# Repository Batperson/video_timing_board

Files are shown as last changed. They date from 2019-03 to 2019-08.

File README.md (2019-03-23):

# Video Timing Board
A Development board to extract timing and subcarrier signals from a composite PAL or NTSC video source.

This is part of my ongoing project to develop a system to superimpose colour text and graphics from a microcontroller onto a composite TV signal. My earlier experimenter's board which can be found at https://github.com/Batperson/video_experimenters_board used a high-speed digital decoder and encoder connected back-to-back, but I now want to try some different methods.

One method is to use an AD724 chip from Analog Devices to generate composite video from RGB signals supplied by a microcontroller. If the AD724 is driven by a clock synchronised with an incoming video signal's colour subcarrier, then its output will also be synchronised with that same subcarrier (i.e. genlocked). Then, a fast switch can be used to switch between the incoming video signal and the text/graphic video signal which we wish to superimpose.

Another method is to generate composite video directly from a microcontroller using the SPI output. Rossum at https://rossumblog.com/2010/06/10/rbox-a-diy-32-bit-game-console-for-the-price-of-a-latte/ has already demonstrated this with the most impressive RBox, a game console based on the Arm Cortex M0 which generates full-colour composite video without any supporting ICs. My theory is that I can do the same, but supply an external clock to the SPI. If this clock is derived from an incoming video signal's colourburst then the output should be genlocked..

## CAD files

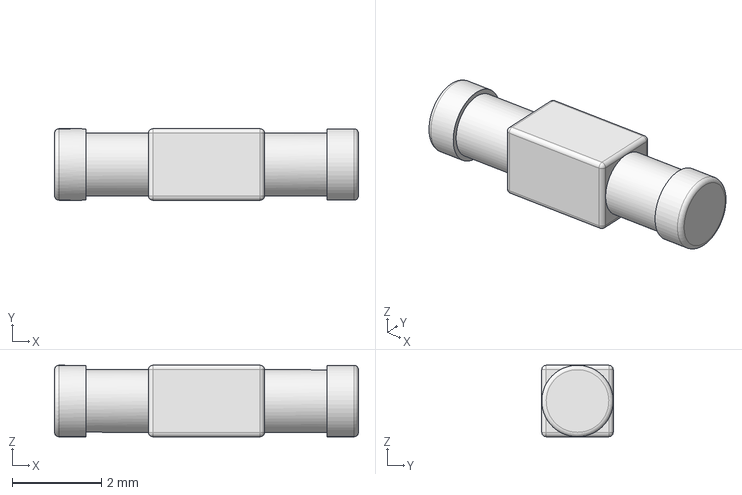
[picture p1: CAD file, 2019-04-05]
3D/NFE61PT472C1H9L.stp
6.80 x 1.60 x 1.60 mm

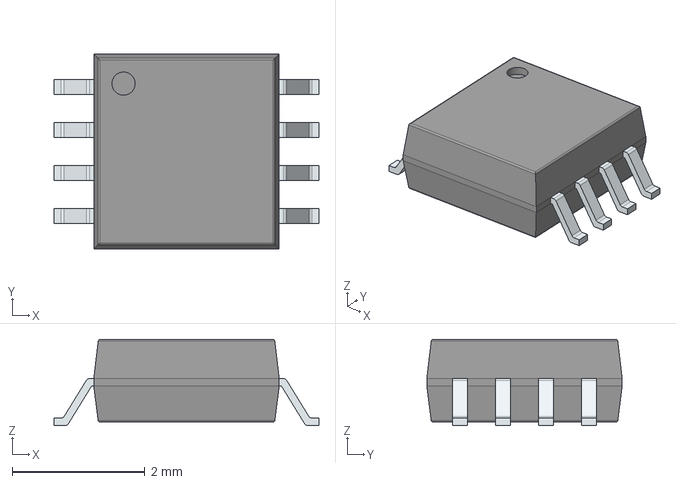
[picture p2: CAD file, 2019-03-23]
3D/SN74LVC3G04DCTR.stp
4.00 x 2.95 x 1.30 mm
PinsArrayLR

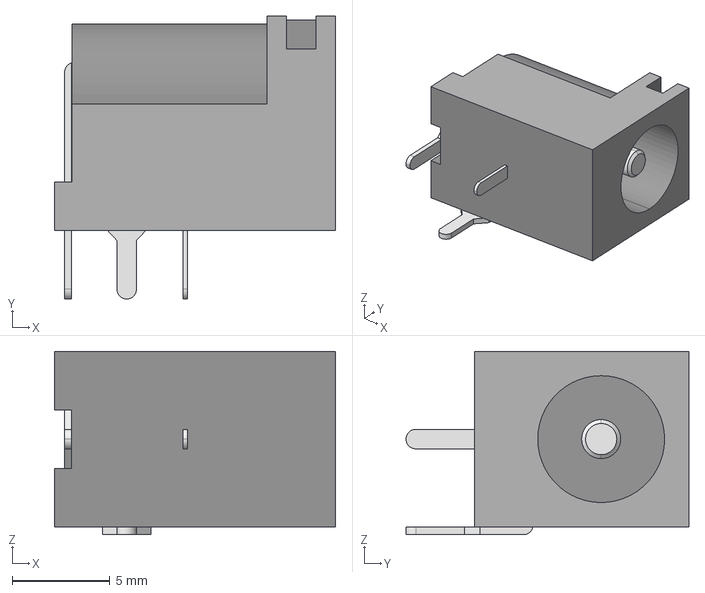
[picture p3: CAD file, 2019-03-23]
3D/PJ-102A.stp
14.4 x 14.5 x 9.40 mm

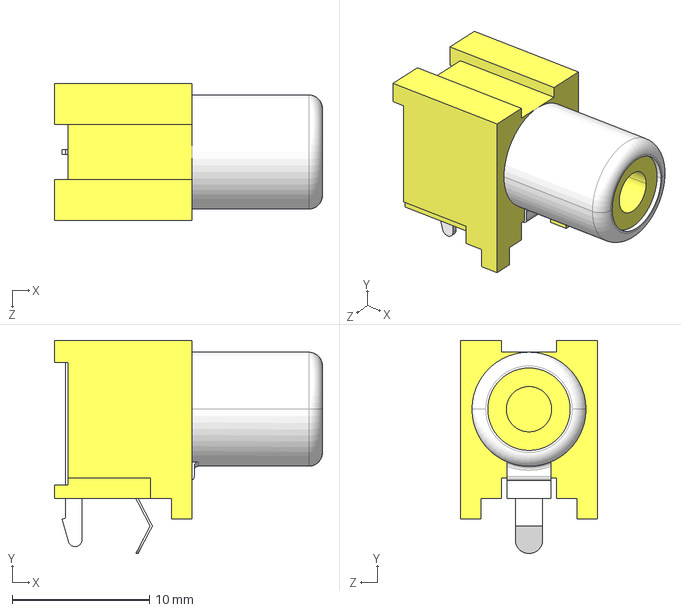
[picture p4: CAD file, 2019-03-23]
3D/CUI_RCJ-044.stp
19.5 x 15.5 x 10.0 mm

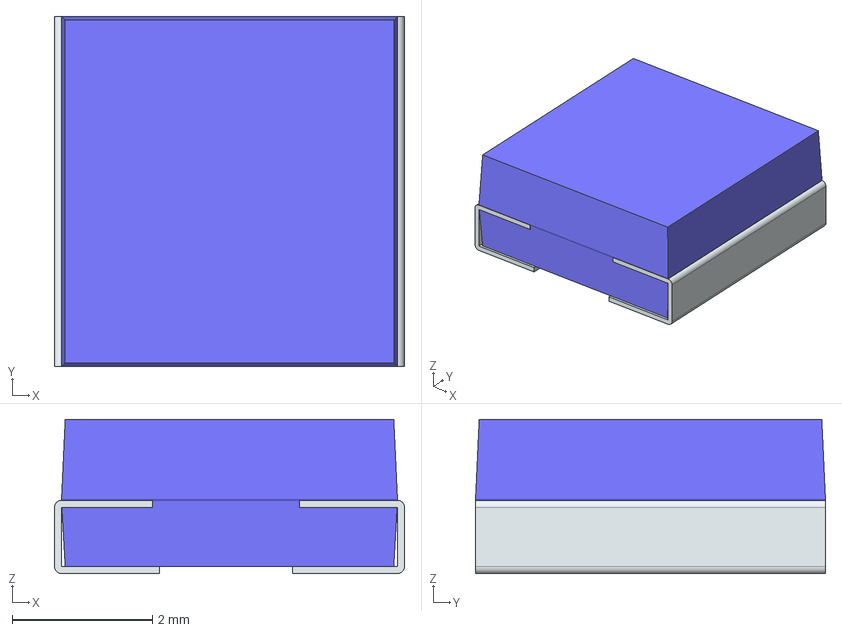
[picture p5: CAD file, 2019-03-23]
3D/LQH5BPN3R3NT0L.stp
5.00 x 5.00 x 2.20 mm
FilletPin1
FilletPin2

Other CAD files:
3D/LQH5BPN3R3NT0L.stl
3D/SN74LVC3G04DCTR.stl

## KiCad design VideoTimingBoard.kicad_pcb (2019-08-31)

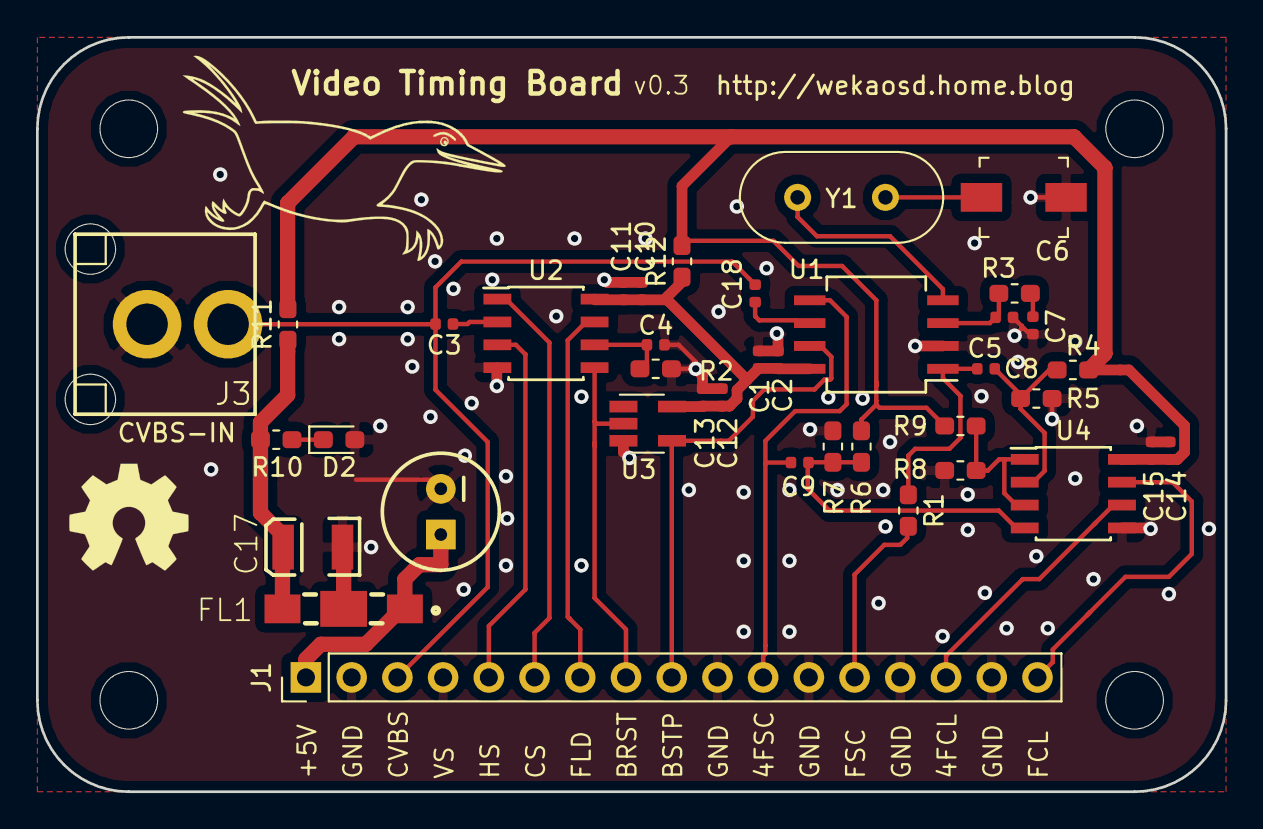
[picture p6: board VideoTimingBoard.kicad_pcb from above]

Board: 2 copper layers, 66.0 x 41.9 mm, 39 parts (0 on the bottom side), 25 nets.

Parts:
C1, C10, C12, C14: 10uF; C_0402_1005Metric
C2, C3, C4, C7, C11, C13, C15, C18: 0.1uF; C_0402_1005Metric
C5: 470pF; C_0402_1005Metric
C6: 5-25pF; C_Trimmer_Murata_TZB4-A
C8, C9: 1nF; C_0402_1005Metric
C16: 220uF; CPOL-RADIAL
C17: 33uF; EIA3528
D2: LED_0603_1608Metric_Pad1.05x0.95mm_HandSolder
FL1: NFE61PT472C1H9L; 6816
J1: PinHeader_1x17_P2.54mm_Vertical
J3: RCA
R1, R11: 0R; R_0603_1608Metric_Pad1.05x0.95mm_HandSolder
R2: 680K; R_0603_1608Metric_Pad1.05x0.95mm_HandSolder
R3: 47K; R_0603_1608Metric_Pad1.05x0.95mm_HandSolder
R4, R5, R6, R7, R8, R9: 10K; R_0603_1608Metric_Pad1.05x0.95mm_HandSolder
R10: 150R; R_0603_1608Metric_Pad1.05x0.95mm_HandSolder
R12: R0; R_0603_1608Metric_Pad1.05x0.95mm_HandSolder
U1: MC44144; SO-8_5.3x6.2mm_P1.27mm
U2: LM1881; SOIC-8_3.9x4.9mm_P1.27mm
U3: SN74LVC1GU04; SOT-23-5_HandSoldering
U4: TLV3502; SOIC-8_3.9x4.9mm_P1.27mm
Y1: Crystal_HC49-U_Vertical

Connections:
+5V: C16.1, FL1.1, J1.1
/4FCLK: J1.15, U4.6
/4FSC: C9.2, J1.11, U1.5
/4FSC-BIAS: C9.1, R6.2, R7.1, U4.4
/BURST: J1.8, U2.5, U3.2
/BURST-INV: J1.9, U1.7, U3.4
/CSYNC: J1.6, U2.1
/CVBS: C3.2, C18.1, J1.3, J3.1
/FCLK: J1.17, U4.7
/FIELD: J1.7, U2.7
/FSC: C8.2, R1.1, U1.1
/FSC1: J1.13, R1.2
/FSC-BIAS: C8.1, R4.2, R5.1, U4.2
/VSYNC: J1.5, U2.3
/XTAL: U1.4, Y1.2
GND: C1.2, C2.2, C4.2, C5.1, C6.1, C7.1, C10.2, C11.1, C12.2, C13.2, C14.1, C15.1, C16.2, C17.2, D2.1, FL1.2, J1.2, J1.4, J1.10, J1.12, J1.14, J1.16, J3.2, R2.2, R5.2, R7.2, R8.1, U1.2, U2.4, U3.3, U4.5
unnamed: C3.1, U2.2
unnamed: C4.1, R2.1, U2.6
unnamed: C5.2, R3.2, U1.3
unnamed: C6.2, Y1.1
unnamed: C7.2, R3.1
unnamed: C18.2, U1.6
unnamed: D2.2, R10.2
unnamed: R8.2, R9.1, U4.1, U4.3
VDD: C1.1, C2.1, C10.1, C11.2, C12.1, C13.1, C14.2, C15.2, C17.1, FL1.3, R4.1, R6.1, R9.2, R10.1, R11.1, R11.2, R12.1, R12.2, U1.8, U2.8, U3.5, U4.8

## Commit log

2019-04-05 Design complete.
    [NFE61PT472C1H9L.stp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]
2019-08-30 Changed .05" pinheaders to .1" Removed CVBS clamp The MC44144 and LM1881 are separately AC-coupled to the CVBS signal.
    [VideoTimingBoard.kicad_pcb, VideoTimingBoard.sch]
2019-08-31 Changed jumpers
    [VideoTimingBoard.kicad_pcb, VideoTimingBoard.sch]
